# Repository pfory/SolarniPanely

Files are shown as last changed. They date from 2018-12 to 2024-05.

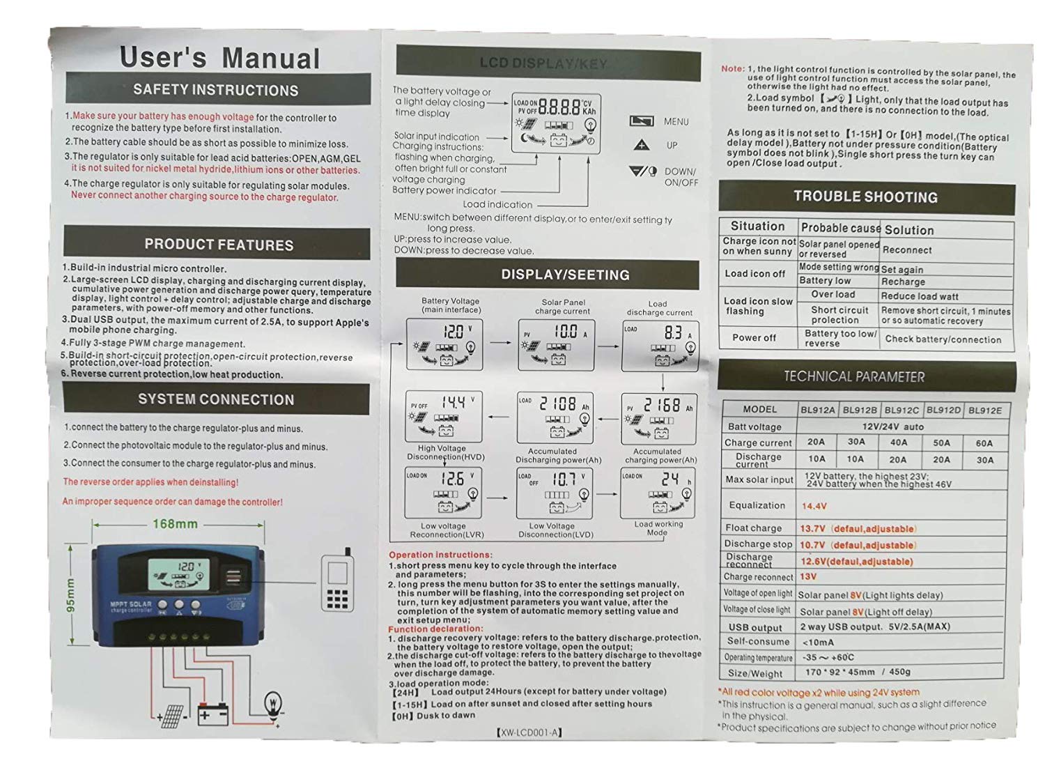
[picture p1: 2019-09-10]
fotovoltaika/manuál.jpg

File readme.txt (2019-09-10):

Odkazy
http://pavelrichter.net/category/projekty/fotovoltaika/
http://blog.chupasweb.net/archives/494
https://www.youtube.com/watch?v=ouLa4Ftu3O8¨

Popis
Solární panel z jednotlivých solárních článků. Ukládání přebytečné energie do baterie, použít autobaterii, později nahradit něčím lepším. Vyrobenou energii měnit na 230V a napájet spotřebiče

Co potřebuji
- solání články + kabely, ebay 5x5" 125x125mm, 2,7W/článek nominální napětí 0,55 - 0,6V/článek 
https://www.ebay.com/itm/2-8W-125MM-Monocrystalline-Solar-Cells-5x5-A-Grade-For-DIY-Solar-Panels/113344175030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
https://www.ebay.com/itm/40Pcs-125MM-Monocrystalline-Silicon-Solar-Cells-For-DIY-Solar-Panels/302911830537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
kolektor 100Wp cca 36ks 9*4 napětí 18V, proud 5,5A 		50ks cena cca 1383,- 
36 článků 996,-

4*125+3*10 =500+30  =530mm   +2*10  +2*19    = 530+20+38 =588mm     590   

9*125+8*1 =1125+8 =1133    +2*10    +2*19    = 1133+20+38=1191mm    1190
                    články  mezera rámeček

rámeček alu profil U 40x25x3 90/m
125+125+62+62=3,75m = 337,-

profil na 2 panely 987 + 140 doprava = 1127
1 panel 560,-

rám 670x1250
sklo 670-2x10=650
1250-2x10=1230

profil pro uchycení na střechu - https://www.ehlinik.cz/al-profil-solar-40x40/pro-2EV0000101.html
délka 2x67 + 2x67 = 4x67 = 268 + mezery 3x2 + kraje 2x5 = 268 + 16 = 284

pro 4 panely zapojené paralelně:
napětí 18V
proud 5,5*4=22A  měl by stačit vodič o průřezu 2,5
výkon 4x100Wp=400Wp

- alu profil https://www.alupa.cz/hlinik/hlinikovy-u-profil-nepr-11x25x13x18/pro-2YS0000101.html 225,-
- sklo 690/m2 panel cca 1m2 - 690,-
- silikon
- regulátor	400,- https://www.ebay.co.uk/itm/10-50A-12-24V-PWM-LCD-Automatic-Solar-Panel-Charger-Controller-Battery-Regulator/122717669692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
- baterie	autobaterie
- měnič 230V
- kabely
- diody
- konektory
- cín
- lepicí páska
- štětec
- nůžky
- ....

Nářadí
- pájka
- svěrák
- pila
- pilník
- šroubovák
- kladivo
- kleště
- klíče

Jeden 100W kolektor by měl za rok vyrobit 80kWh tj. při ceně 6Kč/kWh je cca 480,- za rok

Cenu kolektoru
články 996,-
sklo 782,-
alu profil 350,-
silikon 70,-
tištěné díly + šrouby 50,-

celkem 2248,-

Eko verze s EVA
články 780,-
alu profil 30x20x2 50,7 bez DPH - 3m = 184,-
alu profil 40x20x2 55,9         - 3m = 203,-
doprava 140,-
sklo 4mm cca 115x55 = 380,-
EVA 1000x500*0,4 1m 181,- = 362,-

celkem 780+200+400+362=1742,-

- regulátor 460,-

profil 40x25x3 - 1250
profil 40x25x3 - 620

1.panel
sklo 4mm 65*123
sklo 3mm 65*123
celkem 782,-

2.panel
sklo 4mm 
sklo 3mm 
celkem 782,-

ROZVOD
ze střechy kabelem 4mm do dílny
v dílně baterie, měnič, regulátor a UPS
230 z měniče přes spínací relé do rozvodu UPS
12V přes spínací relé do stávajícího rozvodu 12V

později
dokoupit panely 1 x 115Wp

první panel na střeše jaro 2019
druhý panel na střeše od 16.7.2019
třetí panel - koupeno 15.8.2019 cena 2490,- neosolar.cz na střeše od 20.8.2019

baterie + svorky - koupena 9.9.2019 1197,-

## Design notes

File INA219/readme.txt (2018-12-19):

float getBusVoltage_V(void);  

Reads the voltage between GND and V-.  This is the total voltage seen by the circuit under test.  (Supply voltage - shunt voltage).  

The return value is in Volts.

float getShuntVoltage_mV(void);  

Reads the voltage between V- and V+.  This is the measured voltage drop across the shunt resistor.  

The return value is in Milivolts.

float getCurrent_mA(void);

Reads the current, derived via Ohms Law from the measured shunt voltage.

The return value is in Milliamps.

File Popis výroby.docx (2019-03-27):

Solární články

Použil jsem solární články o rozměru 5x5 palce tj. 125*125mm. Tlouštka článku je 0,2mm a jsou velmi křehké proto je potřeba být při manipulaci maximálně opatrný. Články jsem objednal na ebay, přišly asi za 3týdny. Dodavatel byl sice z Číny, ale na balíčku byla německá adresa. Abych neplatil clo tak jsem rozdělil 50 kusů na dva balíčky ale dodavatel je stejně posla najednou. Cena je závislá na objednávaném množství a pohybuje kolem 20Kč za kus. Je možné objednat pouze články nebo současně i propojovací lišty a fixa s pájecí kapalinou. Tato kapalina usnadňuje pájení, bez ní to jde špatně. Šla by asi použít i klasická kalafuna ale její pozdější odstranění by bylo složitější.

Výkon jednoho článku je 2,8W, napětí kolem 0,5V. Obvykle se používá sériové zapojení 36 článků. Výkon panelu je pak 36*2,8=100W při napětí 18V.

Na články je potřeba naletovat sběrnicové vodiče, což je plochý, pocínovaný pásek o šířce asi 3mm. Ten je dodán navinutý na destičce a šířce jednoho článku takže pak stačí pásek stříhat na délku jednoho obtočení destičky. Při manipulaci s páskem se ho snažíme moc neopokřivit, lépe se pak bude pájet na články.

K pájení používám pájecí pero o výkonu 40W což je pro tento účel dostatečný výkon. Hrot volím co nejmasivnější kvůli akumulaci tepla a široký.

Článek má dvě strany, horní je kladný pól a má obvykle modrou nebo černou barvu, spodní je záporný pól a má obvykle šedou barvu. Na horní straně je po celé šířce článku pájecí ploška, obvykle jsou tam 2, ale mohou být i tři. Na spodní straně není tato pájecí plocha souvislá.

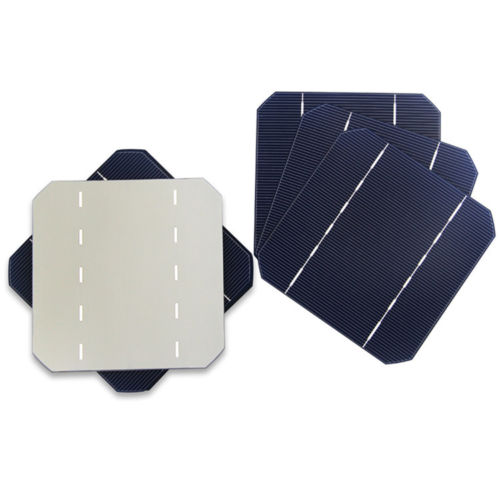
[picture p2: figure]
80Pcs-Mono-Solar-Cells-5x5-For-DIY-Solar-Panels

Solární články, vlevo spodní strana

Postup při pájení je následující:

- panel si položím na stůl kladným pólem nahoru tak aby pájecí plošky byly ve směru, kterým se dívám
- fixem potřu pájecí plošky
- odstřihnu jednu otočku sběrnicového vodiče
- položím na panel tak aby jeden konec byl asi 1 mm od kraje
- vyrovnám sběrnicový vodič tak aby byl nad pájecími ploškami
- zatížím sběrnicový vodič na obou koncích nějakým těžítkem
- na vzdálenější straně nahřeju a připájím asi 1cm sběrnicového vodiče
- odstraním těžítko co je blíž ke mně
- chytím sběrnicový vodič do prstů a začnu směrem k sobě od vzdálenějšího konce pájet
- koriguji umístění pásku

Takto si připravím články pro jeden sloupec. Jelikož jde o panel 36 článků, budou zde 4 sloupce po 9 článcích. Těchto 9 článků spojuji následovně:

- na stůl si položím první článek, záporným pólem nahoru. K němu musím naletovat sběrnicové vodiče, kterými se později připájí k hlavní sběrnici panelu. Tyto pásky jsou dlouhé jako článek s asi 4 cm přesahem. Pásky naletované dříve na kladný pól směřují ke mně.
- na pájecí plošky nanesu fixou pájecí kapalinu
- odstřižený pásek přiložím k první plošce a připájím
- postupně připájím i na ostatní plošky

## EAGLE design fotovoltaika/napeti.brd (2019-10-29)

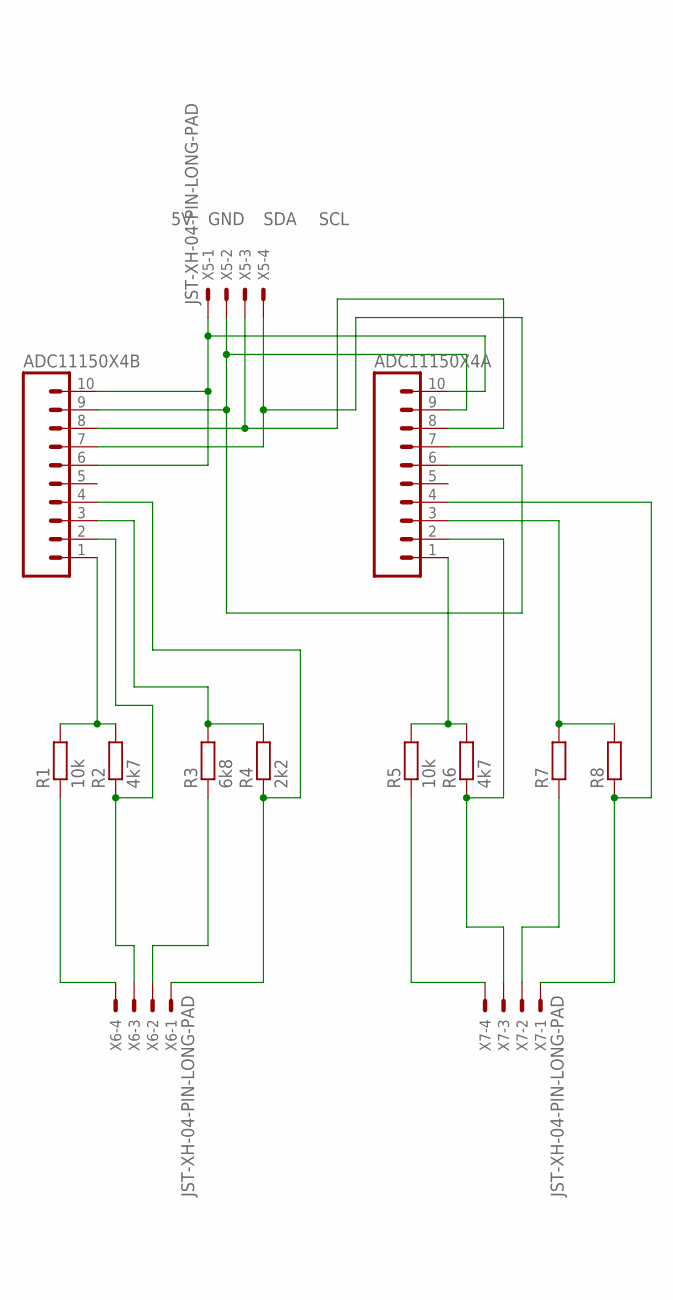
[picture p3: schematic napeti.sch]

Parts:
ADC11150X4A, ADC11150X4B: M10; 10P
R1, R5: 10k; 0204/7
R2, R6: 4k7; 0204/7
R3: 6k8; 0204/7
R4: 2k2; 0204/7
R7, R8: R-EU_0204/7; 0204/7
X5, X6, X7: JST-XH-04-PIN-LONG-PAD; JST-XH-04-PACKAGE-LONG-PAD

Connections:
5V: ADC11150X4A.10, ADC11150X4B.6, ADC11150X4B.10, X5.1
GND: ADC11150X4A.6, ADC11150X4A.9, ADC11150X4B.9, X5.2
unnamed: ADC11150X4A.1, R5.2, R6.2
unnamed: R1.1, X6.4
unnamed: ADC11150X4A.2, R6.1, X7.3
unnamed: ADC11150X4A.3, R7.2, R8.2
unnamed: R3.1, X6.2
unnamed: ADC11150X4A.4, R8.1, X7.1
unnamed: R5.1, X7.4
unnamed: R7.1, X7.2
unnamed: ADC11150X4B.1, R1.2, R2.2
unnamed: ADC11150X4B.2, R2.1, X6.3
unnamed: ADC11150X4B.3, R3.2, R4.2
unnamed: ADC11150X4B.4, R4.1, X6.1
SCL: ADC11150X4A.7, ADC11150X4B.7, X5.4
SDA: ADC11150X4A.8, ADC11150X4B.8, X5.3

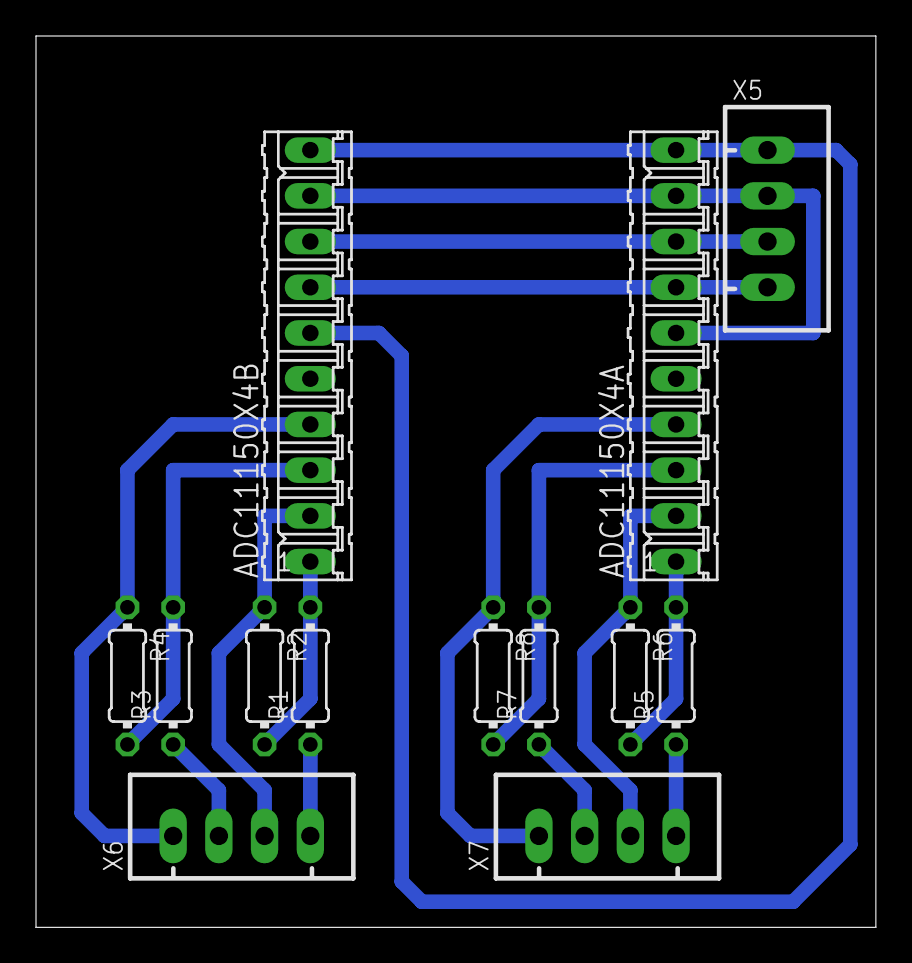
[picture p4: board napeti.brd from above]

Board: 2 copper layers, 46.7 x 49.5 mm, 13 parts (0 on the bottom side), 16 nets.

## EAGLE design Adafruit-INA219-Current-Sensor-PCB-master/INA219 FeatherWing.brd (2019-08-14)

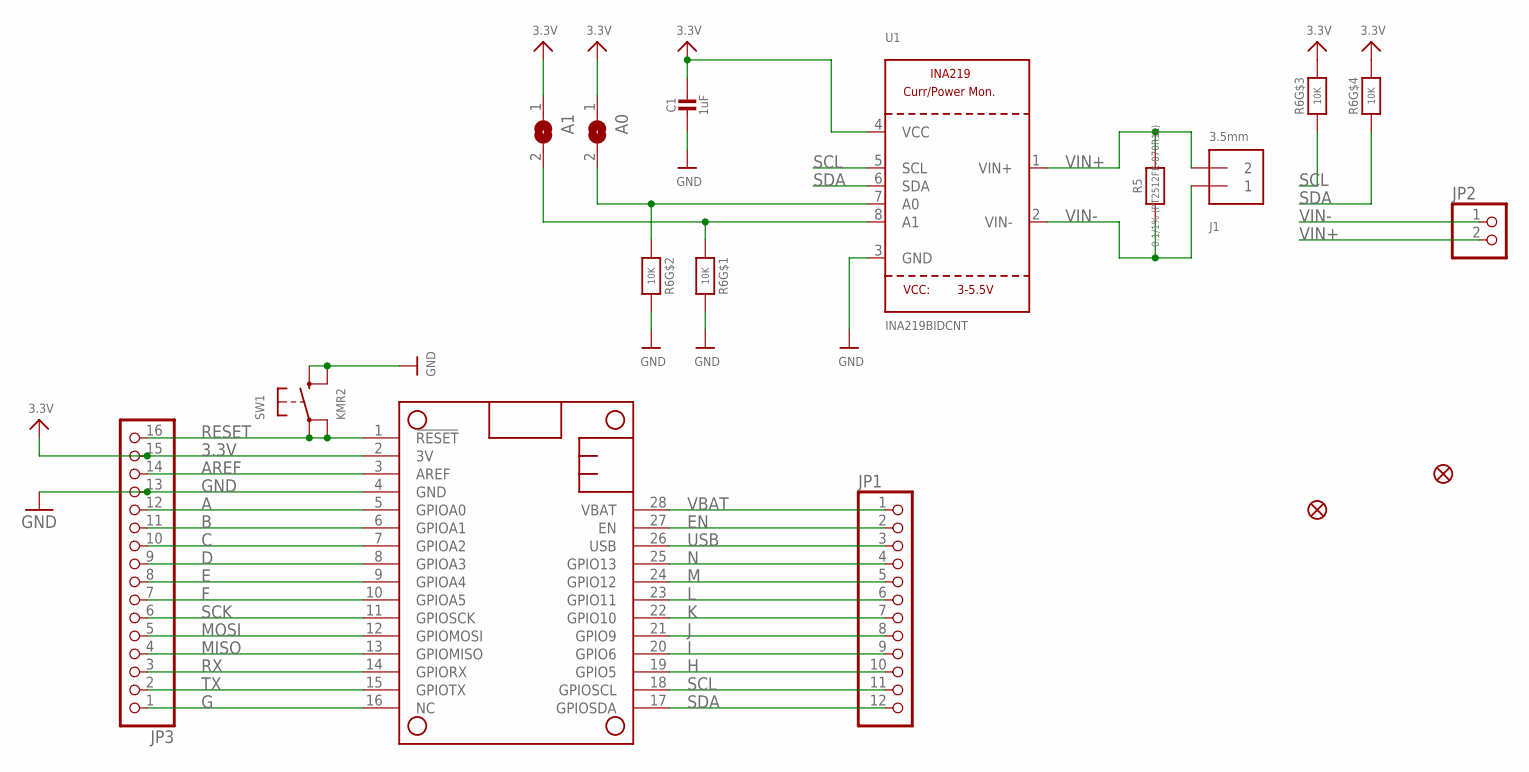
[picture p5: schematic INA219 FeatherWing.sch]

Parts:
A0, A1: SOLDERJUMPERREFLOW_NOPASTE; SOLDERJUMPER_REFLOW_NOPASTE
C1: 1uF; 0805-NO@1
FID1, FID2: FIDUCIAL_1MM
J1: 3.5mm; TERMBLOCK_1X2-3.5MM
JP1: HEADER-1X1276MIL; 1X12_ROUND_76MIL
JP2: HEADER-1X2ROUND; 1X02_ROUND
JP3: HEADER-1X16_76MIL; 1X16_ROUND_76MIL
MS1: FEATHERWING
R5: 0.1/1% (PT2512FK-070R1L); 2512
R6: 10K; RESPACK_4X0603
SW1: KMR2; BTN_KMR2_4.6X2.8
U1: INA219BIDCNT; SOT23-8

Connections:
3.3V: A0.1, A1.1, C1.1, JP3.15, MS1.2 (3V), R6.5 (2), R6.6 (2), U1.4 (VCC)
A: JP3.12, MS1.5 (GPIOA0)
AREF: JP3.14, MS1.3 (AREF)
B: JP3.11, MS1.6 (GPIOA1)
C: JP3.10, MS1.7 (GPIOA2)
D: JP3.9, MS1.8 (GPIOA3)
E: JP3.8, MS1.9 (GPIOA4)
EN: JP1.2, MS1.27 (EN)
F: JP3.7, MS1.10 (GPIOA5)
G: JP3.1, MS1.16 (NC)
GND: C1.2, JP3.13, MS1.4 (GND), R6.7 (2), R6.8 (2), SW1.B (S), SW1.B' (S1), U1.3 (GND)
H: JP1.10, MS1.19 (GPIO5)
I: JP1.9, MS1.20 (GPIO6)
J: JP1.8, MS1.21 (GPIO9)
K: JP1.7, MS1.22 (GPIO10)
L: JP1.6, MS1.23 (GPIO11)
M: JP1.5, MS1.24 (GPIO12)
MISO: JP3.4, MS1.13 (GPIOMISO)
MOSI: JP3.5, MS1.12 (GPIOMOSI)
N: JP1.4, MS1.25 (GPIO13)
unnamed: A1.2, R6.1, U1.8 (A1)
unnamed: A0.2, R6.2 (1), U1.7 (A0)
RESET: JP3.16, MS1.1 (!RESET), SW1.A, SW1.A' (P1)
RX: JP3.3, MS1.14 (GPIORX)
SCK: JP3.6, MS1.11 (GPIOSCK)
SCL: JP1.11, MS1.18 (GPIOSCL), R6.3 (1), U1.5 (SCL)
SDA: JP1.12, MS1.17 (GPIOSDA), R6.4 (1), U1.6 (SDA)
TX: JP3.2, MS1.15 (GPIOTX)
USB: JP1.3, MS1.26 (USB)
VBAT: JP1.1, MS1.28 (VBAT)
VIN+: J1.2, JP2.2, R5.2, U1.1 (VIN+)
VIN-: J1.1, JP2.1, R5.1, U1.2 (VIN-)

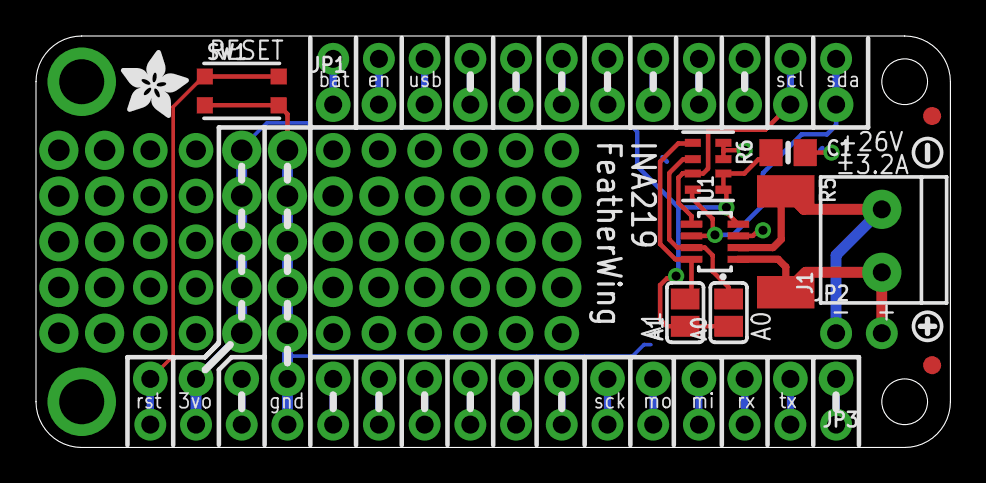
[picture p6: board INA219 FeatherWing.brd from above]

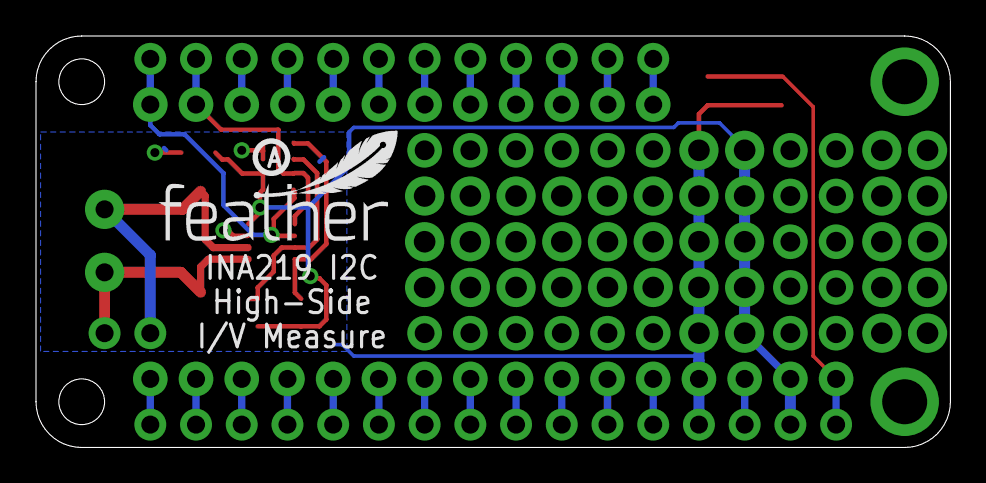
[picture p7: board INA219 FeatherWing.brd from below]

Board: 2 copper layers, 50.8 x 22.9 mm, 19 parts (2 on the bottom side), 32 nets.

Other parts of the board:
U$12: SYMBOL_PLUS
U$13: SYMBOL_MINUS
U$15: FEATHERLOGO_SMALL
U$16: ADAFRUIT_3.5MM
U$17: PCBFEAT-REV-040

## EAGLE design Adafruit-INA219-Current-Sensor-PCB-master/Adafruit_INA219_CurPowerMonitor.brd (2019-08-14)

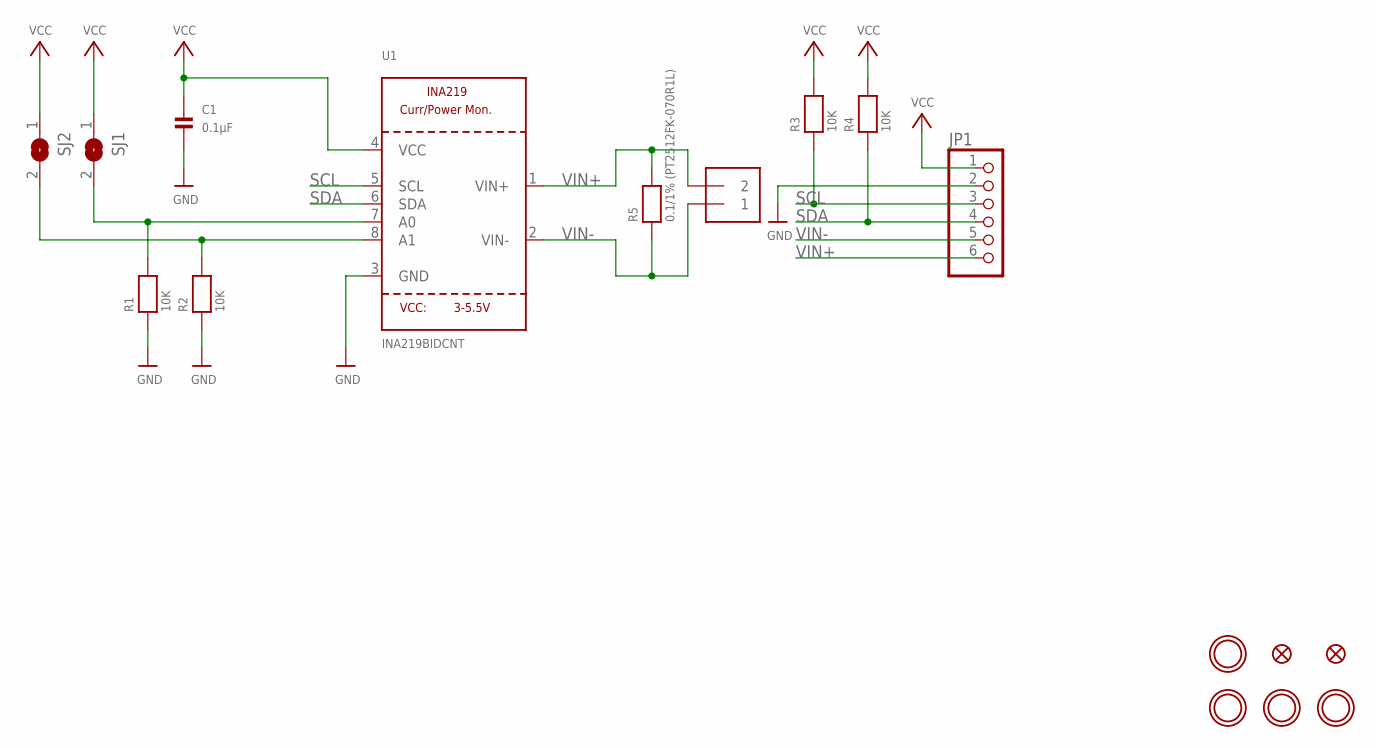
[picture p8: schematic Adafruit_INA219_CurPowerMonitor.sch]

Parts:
C1: 0.1µF; 0805
FID1, FID2: FIDUCIAL""; FIDUCIAL_1MM
J1: TERMBLOCK_1X2-3.5MM; 1X2-3.5MM
JP1: HEADER-1X670MIL; 1X06_ROUND_70
R1, R2, R3, R4: 10K; 0805
R5: 0.1/1% (PT2512FK-070R1L); 2512
SJ1, SJ2: SOLDERJUMPERREFLOW_NOPASTE; SOLDERJUMPER_REFLOW_NOPASTE
U1: INA219BIDCNT; SOT23-8
U$7, U$8, U$9, U$10: MOUNTINGHOLE2.5; MOUNTINGHOLE_2.5_PLATED

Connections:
GND: C1.2, JP1.2, R1.1, R2.1, U1.3 (GND)
unnamed: R2.2, SJ2.2, U1.8 (A1)
unnamed: R1.2, SJ1.2, U1.7 (A0)
SCL: JP1.3, R3.1, U1.5 (SCL)
SDA: JP1.4, R4.1, U1.6 (SDA)
VCC: C1.1, JP1.1, R3.2, R4.2, SJ1.1, SJ2.1, U1.4 (VCC)
VIN+: J1.2, JP1.6, R5.2, U1.1 (VIN+)
VIN-: J1.1, JP1.5, R5.1, U1.2 (VIN-)

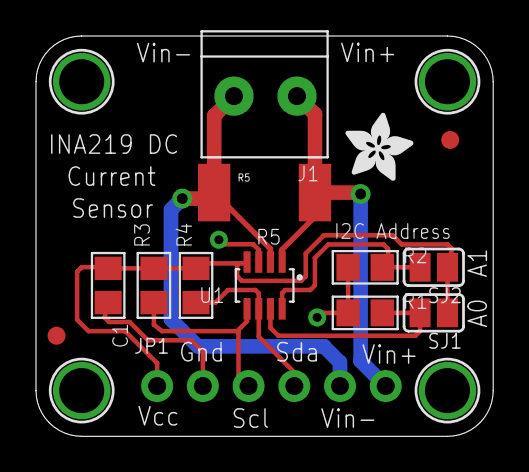
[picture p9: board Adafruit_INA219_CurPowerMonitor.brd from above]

Board: 2 copper layers, 25.4 x 22.2 mm, 18 parts (0 on the bottom side), 8 nets.

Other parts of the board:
U$11: ADAFRUIT_3.5MM

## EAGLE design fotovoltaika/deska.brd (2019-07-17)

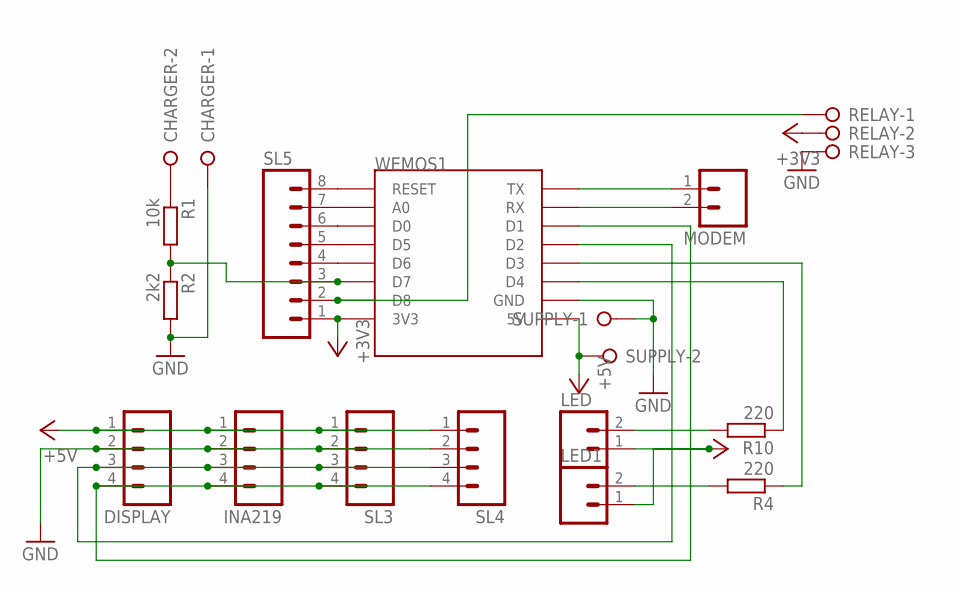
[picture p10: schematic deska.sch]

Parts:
CHARGER: W237-02P; W237-132
DISPLAY: M04; 04P
INA219: M04; 04P
LED, LED1: M02; 02P
MODEM: M02; 02P
R1: 10k; 0207/10
R2: 2k2; 0207/10
R4, R10: 220; 0207/10
RELAY: W237-3E
SL3, SL4: M04; 04P
SL5: M08; 08P
SUPPLY: W237-02P; W237-132
WEMOS1: WEMOS-D1-MINI

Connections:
+3V3: RELAY.2, SL5.1, WEMOS1.3V3
+5V: DISPLAY.1, INA219.1, LED.1, LED1.1, SL3.1, SL4.1, SUPPLY.2, WEMOS1.5V
GND: CHARGER.1, DISPLAY.2, INA219.2, R2.2, RELAY.3, SL3.2, SL4.2, SUPPLY.1, WEMOS1.GND
unnamed: DISPLAY.4, INA219.4, SL3.4, SL4.4, WEMOS1.D1
unnamed: DISPLAY.3, INA219.3, SL3.3, SL4.3, WEMOS1.D2
unnamed: SL5.7, WEMOS1.A0
unnamed: RELAY.1, SL5.2, WEMOS1.D8
unnamed: CHARGER.2, R1.1
unnamed: SL5.4, WEMOS1.D6
unnamed: SL5.5, WEMOS1.D5
unnamed: SL5.6, WEMOS1.D0
unnamed: R1.2, R2.1, SL5.3, WEMOS1.D7
unnamed: R10.1, WEMOS1.D4
unnamed: LED.2, R10.2
unnamed: SL5.8, WEMOS1.RESET
unnamed: MODEM.1, WEMOS1.TX
unnamed: MODEM.2, WEMOS1.RX
unnamed: LED1.2, R4.2
unnamed: R4.1, WEMOS1.D3

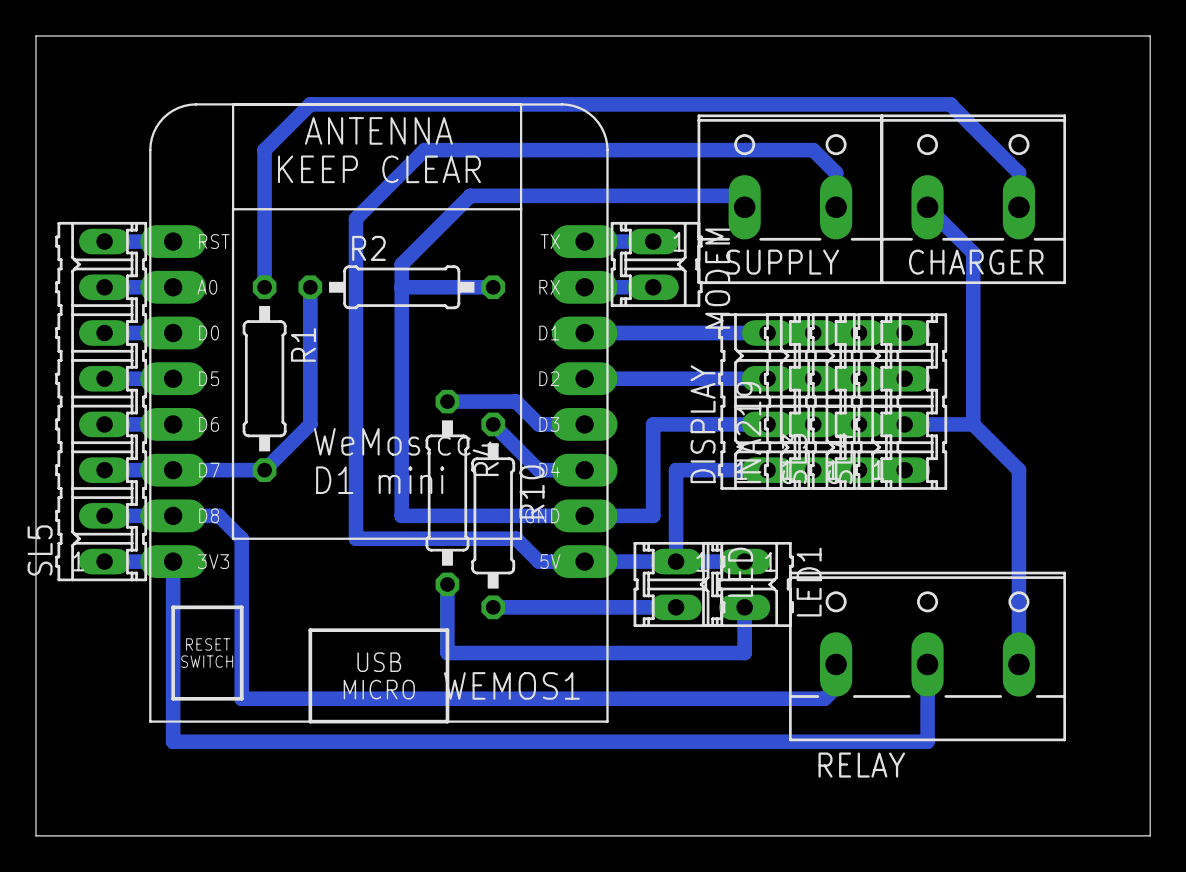
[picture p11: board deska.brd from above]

Board: 2 copper layers, 61.9 x 44.4 mm, 16 parts (0 on the bottom side), 19 nets.

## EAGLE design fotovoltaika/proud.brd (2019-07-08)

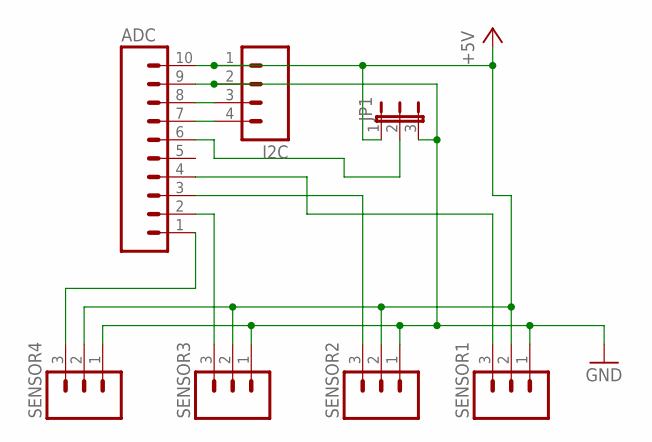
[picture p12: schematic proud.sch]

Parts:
ADC: M10; 10P
I2C: M04; 04P
JP1: JP2E; JP2
SENSOR1, SENSOR2, SENSOR3, SENSOR4: M03; 03P

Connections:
+5V: ADC.10, I2C.1, JP1.1, SENSOR1.2, SENSOR2.2, SENSOR3.2, SENSOR4.2
GND: ADC.9, I2C.2, JP1.3, SENSOR1.1, SENSOR2.1, SENSOR3.1, SENSOR4.1
unnamed: ADC.1, SENSOR4.3
unnamed: ADC.8, I2C.3
unnamed: ADC.2, SENSOR3.3
unnamed: ADC.3, SENSOR2.3
unnamed: ADC.4, SENSOR1.3
unnamed: ADC.7, I2C.4
unnamed: ADC.6, JP1.2

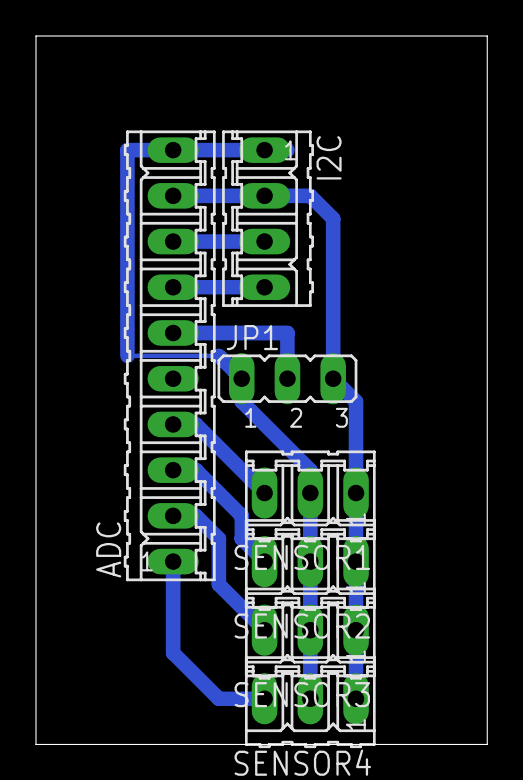
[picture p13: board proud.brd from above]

Board: 2 copper layers, 25.1 x 39.4 mm, 7 parts (0 on the bottom side), 9 nets.

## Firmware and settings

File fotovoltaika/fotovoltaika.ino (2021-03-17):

/*HW
  mereni proudu na regulatoru
    - vstup z FW panelu, cidlo s  ACS758LCB-050B +-50A  40mV/A
    - akumulator, cidlo s         ACS712 +-20A          100mV/A
    - vystup, cidlo s             ACS712 +-5A           185mV/A
    vsechna cidla jsou pripojena na vstupy AD prevodniku s ADS1115, vystup I2C SDA - D2, SCL - D1
  mereni napeti na regulatoru, spolecny je + pol, proti zemi je max na vstupu z panelu tj.20V

 
  display - 20x4
  ESP8266 - Wemos
  
  větev baterie - měnič
  odběr na prázdno      0,18A   2,2W
  bez čerpadla soláru   1,36A  16,3W
  s čerpadlem soláru    3,87A  46,5W
  
*/

#include "Configuration.h"

#define time
#ifdef time
#include <TimeLib.h>
#include <Timezone.h>
WiFiUDP EthernetUdp;
static const char     ntpServerName[]       = "tik.cesnet.cz";
//const int timeZone = 2;     // Central European Time
//Central European Time (Frankfurt, Paris)
TimeChangeRule        CEST                  = {"CEST", Last, Sun, Mar, 2, 120};     //Central European Summer Time
TimeChangeRule        CET                   = {"CET",  Last, Sun, Oct, 3, 60 };     //Central European Standard Time
Timezone CE(CEST, CET);
unsigned int          localPort             = 8888;  // local port to listen for UDP packets
time_t getNtpTime();
#define TIMEX   0
#define TIMEY   3
#endif

//voltage and current meassurement
Adafruit_ADS1115 ads1(0x48);  //mereni proudu ADDR to GND - pravý
Adafruit_ADS1115 ads2(0x49);  //mereni napeti ADDR to VCC - levý
//Adafruit_ADS1115 ads3(0x4B);  //mereni napeti ADDR to SCL


#include <LiquidCrystal_I2C.h>
LiquidCrystal_I2C lcd(LCDADDRESS,LCDCOLS,LCDROWS);  // set the LCD
#define PRINT_SPACE  lcd.print(" ");
volatile bool showDoubleDot                 = false;
unsigned int display                        = 0;
#define DISPLAY_MAIN                         0

//navrhar - https://maxpromer.github.io/LCD-Character-Creator/
byte customChar[] = {
  B01110,
  B01010,
  B01110,
  B00000,
  B00000,
  B00000,
  B00000,
  B00000
};

//for LED status
Ticker ticker;

bool isDebugEnabled()
{
#ifdef verbose
  return true;
#endif // verbose
  return false;
}


float   relayONVoltageBig           = 13.5;
float   relayONVoltageSmall         = 12.5;
float   relayOFFVoltage             = 11.f;


byte relayStatus                    = RELAY_OFF;
byte relayMode                      = RELAY_MODE_AUTO;
  
int duvodZmenyStavuRele             = 0;
//ADC_MODE(ADC_VCC);

uint32_t heartBeat                  = 0;

//mereni napeti   
float      voltageRegInMin          = MAX; //vystup z panelu, rozsah 0-20V
float      voltageRegIn             = 12.f; 
float      voltageRegOutMin         = MAX; //vystup z regulatoru, rozsah 0-15V
float      voltageRegInMax          = MIN; //vystup z panelu, rozsah 0-20V
float      voltageRegOutMax         = MIN; //vystup z regulatoru, rozsah 0-15V
float      voltageRegOut            = 12.f; 
float      voltageSupply            = MIN;
float      forecastedEnergyTomorrow = -1.f;  
uint32_t  lastReadADC               = 0;              //interval mezi ctenim sensoru

//mereni proudu
float     currentRegIn              = 0.f;   //Ampers
float     currentRegOut             = 0.f;
      
float     currentRegInSum           = 0.f;
float     currentRegOutSum          = 0.f;
int32_t   intervalMSec              = 0;

long      runSecToday               = 0;
float     AhPanelToday              = 0;
float     AhOutToday                = 0;

bool      todayClear                = false;
bool      dispClear                 = false;

float     lastRelayOff              = 0;


DoubleResetDetector drd(DRD_TIMEOUT, DRD_ADDRESS);


//Adafruit_INA219 ina219_2; //intput
//Adafruit_INA219 ina219_1(0x41); //output

//gets called when WiFiManager enters configuration mode
void configModeCallback (WiFiManager *myWiFiManager) {
  DEBUG_PRINTLN("Entered config mode");
  DEBUG_PRINTLN(WiFi.softAPIP());
  //if you used auto generated SSID, print it
  DEBUG_PRINTLN(myWiFiManager->getConfigPortalSSID());
  //entered config mode, make led toggle faster
  ticker.attach(0.2, tick);
  drd.stop();
}

#include <timer.h>
auto timer = timer_create_default(); // create a timer with default settings
Timer<> default_timer; // save as above


void tick()
{
  //toggle state
  int state = digitalRead(BUILTIN_LED);  // get the current state of GPIO1 pin
  digitalWrite(BUILTIN_LED, !state);     // set pin to the opposite state
  digitalWrite(STATUS_LED, !state);          // set pin to the opposite state
}


//MQTT callback
void callback(char* topic, byte* payload, unsigned int length) {
  char * pEnd;
  long int valL;
  String val =  String();
  DEBUG_PRINT("Message arrived [");
  DEBUG_PRINT(topic);
  DEBUG_PRINT("] ");
  for (int i=0;i<length;i++) {
    DEBUG_PRINT((char)payload[i]);
    val += (char)payload[i];
  }
  DEBUG_PRINTLN();
  
  if (strcmp(topic, (String(mqtt_base) + "/cmnd/" + String(mqtt_topic_relay)).c_str())==0) {
    printMessageToLCD(topic, val);
    DEBUG_PRINT("set manual control relay to ");
    relayMode = val.toInt();
    if (val.toInt()==1) {
      DEBUG_PRINTLN(F("ON"));
    } else if (val.toInt()==0) {
      DEBUG_PRINTLN(F("OFF"));
    } else {
      DEBUG_PRINTLN(F("AUTO"));
    }
  } else if (strcmp(topic, (String(mqtt_base) + "/" + String(mqtt_topic_restart)).c_str())==0) {
    printMessageToLCD(topic, val);
    DEBUG_PRINT("RESTART");
    ESP.restart();
  } else if (strcmp(topic, mqtt_topic_weather)==0) {
    DEBUG_PRINT("Temperature from Meteo: ");
    DEBUG_PRINTLN(val.toFloat());
    //displayValue(TEMPERATURE_X,TEMPERATURE_Y, (int)round(val.toFloat()), 3, 0);
    //lcd.write(byte(0));
    //lcd.print("C");
  } else if (strcmp(topic, (String(mqtt_base) + "/" + String(mqtt_topic_relayOFFVoltage)).c_str())==0) {
    printMessageToLCD(topic, val);
    DEBUG_PRINT("set OFF voltage to ");
    relayOFFVoltage = val.toFloat();
    saveConfig();
  } else if (strcmp(topic, (String(mqtt_base) + "/" + String(mqtt_topic_relayONVoltageBig)).c_str())==0) {
    printMessageToLCD(topic, val);
    DEBUG_PRINT("set ON big voltage to ");
    relayONVoltageBig = val.toFloat();
    saveConfig();
  } else if (strcmp(topic, (String(mqtt_base) + "/" + String(mqtt_topic_forecast)).c_str())==0) {
    DEBUG_PRINT("Forecast from solcast ");
    lcd.setCursor(FORECAST_X-3,FORECAST_Y);
    lcd.print("FP:");
    displayValue(FORECAST_X,FORECAST_Y, val.toFloat(), 2, 1);
    forecastedEnergyTomorrow = val.toFloat();
    lcd.print("kWh");
  } else if (strcmp(topic, (String(mqtt_base) + "/" + String(mqtt_topic_relayONVoltageSmall)).c_str())==0) {
    printMessageToLCD(topic, val);
    DEBUG_PRINT("set ON small voltage to ");
    relayONVoltageSmall = val.toFloat();
    saveConfig();
  }
}

void printMessageToLCD(char* t, String v) {
  lcd.clear();
  lcd.print(t);
  lcd.print(": ");
  lcd.print(v);
  delay(2000);
  lcd.clear();
}


WiFiClient espClient;
PubSubClient client(espClient);

void setup() {
  SERIAL_BEGIN;
  DEBUG_PRINT(F(SW_NAME));
  DEBUG_PRINT(F(" "));
  DEBUG_PRINTLN(F(VERSION));

  WiFiManager wifiManager;

  if (drd.detectDoubleReset()) {
    DEBUG_PRINTLN("Double reset detected, starting config portal...");
    if (!wifiManager.startConfigPortal(HOSTNAMEOTA)) {
      DEBUG_PRINTLN("failed to connect and hit timeout");
      delay(3000);
      //reset and try again, or maybe put it to deep sleep
      ESP.reset();
      delay(5000);
    }
  }

  lcd.init();               // initialize the lcd 
  lcd.backlight();
  //lcd.begin();               // initialize the lcd 
  lcd.home();                   
  lcd.print(SW_NAME);  
  PRINT_SPACE
  lcd.print(VERSION);
  lcd.createChar(0, customChar);

  pinMode(BUILTIN_LED, OUTPUT);
  pinMode(STATUS_LED, OUTPUT);
  pinMode(LED2PIN, OUTPUT);
  digitalWrite(STATUS_LED, HIGH); //nesviti
  digitalWrite(LED2PIN, HIGH);
  pinMode(RELAY1PIN, OUTPUT);
  pinMode(RELAY2PIN, OUTPUT);
  digitalWrite(RELAY1PIN, relayStatus);
  digitalWrite(RELAY2PIN, relayStatus);
  pinMode(PIRPIN, INPUT);
  //attachInterrupt(digitalPinToInterrupt(PIRPIN), PIREvent, CHANGE);

  rst_info *_reset_info = ESP.getResetInfoPtr();
  uint8_t _reset_reason = _reset_info->reason;
  DEBUG_PRINT("Boot-Mode: ");
  DEBUG_PRINTLN(_reset_reason);
  heartBeat = _reset_reason;
  
  /*
 REASON_DEFAULT_RST             = 0      normal startup by power on 
 REASON_WDT_RST                 = 1      hardware watch dog reset 
 REASON_EXCEPTION_RST           = 2      exception reset, GPIO status won't change 
 REASON_SOFT_WDT_RST            = 3      software watch dog reset, GPIO status won't change 
 REASON_SOFT_RESTART            = 4      software restart ,system_restart , GPIO status won't change 
 REASON_DEEP_SLEEP_AWAKE        = 5      wake up from deep-sleep 
 REASON_EXT_SYS_RST             = 6      external system reset 
  */
  client.setServer(mqtt_server, mqtt_port);
  client.setCallback(callback);

  ticker.attach(1, tick);

  WiFi.printDiag(Serial);
    
  bool validConf = readConfig();
  if (!validConf) {
    DEBUG_PRINTLN(F("ERROR config corrupted"));
  }
  
  //reset settings - for testing
  //wifiManager.resetSettings();
  
  IPAddress _ip,_gw,_sn;
  _ip.fromString(static_ip);
  _gw.fromString(static_gw);
  _sn.fromString(static_sn);

  wifiManager.setSTAStaticIPConfig(_ip, _gw, _sn);
  
  DEBUG_PRINTLN(_ip);
  DEBUG_PRINTLN(_gw);
  DEBUG_PRINTLN(_sn);

  wifiManager.setConfigPortalTimeout(CONFIG_PORTAL_TIMEOUT);
  wifiManager.setConnectTimeout(CONNECT_TIMEOUT);
  //set callback that gets called when connecting to previous WiFi fails, and enters Access Point mode
  wifiManager.setAPCallback(configModeCallback);

  if (!wifiManager.autoConnect(AUTOCONNECTNAME, AUTOCONNECTPWD)) { 
    DEBUG_PRINTLN("failed to connect and hit timeout");
    delay(3000);
    //reset and try again, or maybe put it to deep sleep
    ESP.reset();
    delay(5000);
  } 
  
#ifdef time
  DEBUG_PRINTLN("Setup TIME");
  lcd.setCursor(0,1);
  lcd.print("Setup time...");
  EthernetUdp.begin(localPort);
  DEBUG_PRINT("Local port: ");
  DEBUG_PRINTLN(EthernetUdp.localPort());
  DEBUG_PRINTLN("waiting for sync");
  setSyncProvider(getNtpTime);
  setSyncInterval(300);
  
  printSystemTime();
#endif

  
#ifdef ota
  ArduinoOTA.setHostname(HOSTNAMEOTA);
  ArduinoOTA.onStart([]() {
    DEBUG_PRINTLN("Start updating ");
  });
  ArduinoOTA.onEnd([]() {
   DEBUG_PRINTLN("\nEnd");
  });
  ArduinoOTA.onProgress([](unsigned int progress, unsigned int total) {
    DEBUG_PRINTF("Progress: %u%%\r", (progress / (total / 100)));
  });
  ArduinoOTA.onError([](ota_error_t error) {
    DEBUG_PRINTF("Error[%u]: ", error);
    if (error == OTA_AUTH_ERROR) DEBUG_PRINTLN("Auth Failed");
    else if (error == OTA_BEGIN_ERROR) DEBUG_PRINTLN("Begin Failed");
    else if (error == OTA_CONNECT_ERROR) DEBUG_PRINTLN("Connect Failed");
    else if (error == OTA_RECEIVE_ERROR) DEBUG_PRINTLN("Receive Failed");
    else if (error == OTA_END_ERROR) DEBUG_PRINTLN("End Failed");
  });
  ArduinoOTA.begin();
#endif

  // The ADC input range (or gain) can be changed via the following
  // functions, but be careful never to exceed VDD +0.3V max, or to
  // exceed the upper and lower limits if you adjust the input range!
  // Setting these values incorrectly may destroy your ADC!
  //ADS1015 - 12bit = 4096
  //ADS1115 - 16bit = 65536
  //                                                             ADS1015         ADS1115
  //                                                             -------         -------
  ads1.setGain(GAIN_TWOTHIRDS);        // 2/3x gain +/- 6.144V  1 bit = 3mV      0.1875mV (default)
  ads2.setGain(GAIN_TWOTHIRDS);        // 2/3x gain +/- 6.144V  1 bit = 3mV      0.1875mV (default)
  //ads3.setGain(GAIN_TWOTHIRDS);        // 2/3x gain +/- 6.144V  1 bit = 3mV      0.1875mV (default)
  // ads.setGain(GAIN_ONE);            // 1x gain   +/- 4.096V  1 bit = 2mV      0.125mV
  // ads.setGain(GAIN_TWO);            // 2x gain   +/- 2.048V  1 bit = 1mV      0.0625mV
  // ads.setGain(GAIN_FOUR);           // 4x gain   +/- 1.024V  1 bit = 0.5mV    0.03125mV
  // ads.setGain(GAIN_EIGHT);          // 8x gain   +/- 0.512V  1 bit = 0.25mV   0.015625mV
  // ads.setGain(GAIN_SIXTEEN);        // 16x gain  +/- 0.256V  1 bit = 0.125mV  0.0078125mV
  ads1.begin();
  ads2.begin();
  //ads3.begin();
  
    // Initialize the INA219.
  // By default the initialization will use the largest range (32V, 2A).  However
  // you can call a setCalibration function to change this range (see comments).
  //ina219_1.begin();
  //ina219_2.begin();
  // To use a slightly lower 32V, 1A range (higher precision on amps):
  //ina219_1.setCalibration_16V_400mA();
  //ina219_2.setCalibration_32V_2A();
  // Or to use a lower 16V, 400mA range (higher precision on volts and amps):
  //ina219.setCalibration_16V_400mA();
  
  //setup timers
  timer.every(SEND_DELAY, sendDataHA);
  timer.every(SENDSTAT_DELAY, sendStatisticHA);
  timer.every(READADC_DELAY, readADC);
  timer.every(1000, calcStat);
#ifdef time  
  timer.every(500, displayTime);
#endif
  void * a;
  sendStatisticHA(a);

  ticker.detach();
  //keep LED on
  digitalWrite(BUILTIN_LED, HIGH);
  digitalWrite(STATUS_LED, HIGH);
  lcd.clear();
  lcd.setCursor(RELAY_STATUSX,RELAY_STATUSY);
  lcd.print("OFF");
}

void loop() {
  drd.loop();
  timer.tick(); // tick the timer
#ifdef ota
  ArduinoOTA.handle();
#endif

  if (digitalRead(PIRPIN)==1) {
    lcd.backlight();
  } else {
    lcd.noBacklight();
  }

  if (!client.connected()) {
    reconnect();
  }
  client.loop();

  relay();
 
  nulStat();
  displayClear();

  drd.stop();
 
}

//---------------------------------------------R E L A Y ------------------------------------------------
void relay() {
  if (relayMode==RELAY_MODE_AUTO) {
    if (millis() - lastRelayOff > RELAYDELAYOFFON) {
      //-----------------------------------zmena 0-1--------------------------------------------
      if (relayStatus == RELAY_OFF) {
        bool zapni=false;
        if (voltageRegOut > relayONVoltageBig) { //voltageRegOut > 13.5
          duvodZmenyStavuRele=1;
          zapni = true;
        } else if (currentRegIn > CURRENT4ONBIG) { //currentRegIn > 6
          duvodZmenyStavuRele=2;
          zapni = true;
        } else if (currentRegIn > CURRENT4ONSMALL && voltageRegOut >= relayONVoltageSmall) { //currentRegIn > 4) && voltageRegOut >= 12.5
          duvodZmenyStavuRele=3;
          zapni = true;
        }
        if (zapni) {
          relayStatus = RELAY_ON;
          changeRelay(relayStatus);
          sendRelayHA(1);
        }
      //-----------------------------------zmena 1-0--------------------------------------------
      } else if (relayStatus == RELAY_ON) {
        bool vypni=false;
        if (voltageRegOut <= relayOFFVoltage) { //voltageRegOut <= 11.0
          duvodZmenyStavuRele=4;
          vypni = true;
        } else if (forecastedEnergyTomorrow < FORECASTED_LIMIT_OFF && currentRegIn < CURRENT4ONSMALL && voltageRegOut < relayONVoltageSmall) { //forecastedEnergyTomorrow < 0.06 && currentRegIn < 2 && voltageRegOut < 12.5
          duvodZmenyStavuRele=5;
          vypni = true;
        //} else if (currentRegIn < currentRegOut && voltageRegOut < relayONVoltageSmall) { //currentRegIn < currentRegOut && voltageRegOut < 12.5
        //  duvodZmenyStavuRele=6;
        //  vypni = true;
        }
        if (vypni) {
          relayStatus = RELAY_OFF;
          changeRelay(relayStatus);
          sendRelayHA(0);
          lastRelayOff = millis();
        }
      }
      if (duvodZmenyStavuRele==-1) {
        duvodZmenyStavuRele=0;
      }
    } else {
      duvodZmenyStavuRele=-1;
    }
  } else if (relayStatus == RELAY_OFF && relayMode==RELAY_MODE_ON) {
      relayStatus = RELAY_ON;
      changeRelay(relayStatus);
      duvodZmenyStavuRele=7;
      sendRelayHA(1);
  } else if (relayStatus == RELAY_ON && relayMode==RELAY_MODE_OFF) {
      relayStatus = RELAY_OFF;
      changeRelay(relayStatus);
      duvodZmenyStavuRele=8;
      sendRelayHA(1);
  }
  dispRelayStatus();
}


void nulStat() {
 //nulovani statistik o pulnoci
  if (hour()==0 && !todayClear) {
    todayClear =true;
    runSecToday = 0;
    AhPanelToday = 0;
  } else if (hour()>0) {
    todayClear = false;
  }
}

void displayClear() {
  if (minute()==0 && second()==0) {
    if (!dispClear) { 
      lcd.clear();
      dispClear = true;
    }
  } else {
    dispClear = false;
  }
}

bool readADC(void *) {

  int32_t dilkuSupply            = ads1.readADC_SingleEnded(CHANNEL_VOLTAGE_SUPPLY);
  int32_t dilkuInputCurrent      = ads1.readADC_SingleEnded(CHANNEL_REG_IN_CURRENT);
  int32_t dilkuOutputCurrent     = ads1.readADC_SingleEnded(CHANNEL_REG_OUT_CURRENT);
  // DEBUG_PRINT("dilkuSupply:");
  // DEBUG_PRINT(dilkuSupply);
  // DEBUG_PRINT(", dilkuInputCurrent:");
  // DEBUG_PRINT(dilkuInputCurrent);
  // DEBUG_PRINT(", dilkuOutputCurrent:");
  // DEBUG_PRINTLN(dilkuOutputCurrent);
  
  voltageSupply    = ((float)dilkuSupply * MVOLTDILEKADC1); //in mV  example 26149 * 0.1875 = 4902,938mV
  // DEBUG_PRINT("voltageSupply:");
  // DEBUG_PRINTLN(voltageSupply);

  int32_t dilkuInputVoltage      = ads2.readADC_Differential_0_1();  //solar panel
  int32_t dilkuOutputVoltage     = ads2.readADC_Differential_2_3();  //output
  // DEBUG_PRINT("dilkuInputVoltage:");
  // DEBUG_PRINT(dilkuInputVoltage);
  // DEBUG_PRINT(", dilkuOutputVoltage:");
  // DEBUG_PRINT(dilkuOutputVoltage);
  
  float loadvoltage = (dilkuOutputVoltage * MVOLTDILEKADC2 * KOEF_OUTPUT_VOLTAGE) / V2MV; // 13.0f;
  
  if (loadvoltage > MIN && loadvoltage < MAX) {
    voltageRegOut = loadvoltage;
    voltageRegOutMin   = min(loadvoltage, voltageRegOutMin);
    voltageRegOutMax   = max(loadvoltage, voltageRegOutMax);
    // DEBUG_PRINTLN(voltageRegOutMin);
    // DEBUG_PRINTLN(voltageRegOutMax);
  }

  loadvoltage = dilkuOutputVoltage * MVOLTDILEKADC2 * KOEF_INPUT_VOLTAGE; // 13.0f;
  if (loadvoltage > MIN && loadvoltage < MAX) {
    voltageRegIn = 12.f; //loadvoltage;
    voltageRegInMin    = 12.f; //min(loadvoltage, voltageRegIMin);
    voltageRegInMax    = 12.f; //max(loadvoltage, voltageRegInMax);
  }
  
  if (lastReadADC==0) {
    lastReadADC = millis();
  }
  
  uint32_t diff = millis()-lastReadADC;
  
  currentRegIn  = ((float)(dilkuInputCurrent * 2 - dilkuSupply) * MVOLTDILEKADC1) / MVAMPERIN / 2; //in Amp example ((15170 * 2 - 25852) * 0.1875) / 40 = ((30340 - 25852) * 0.1875) / 40 = 4488 * 0.1875 / 40
  currentRegInSum += currentRegIn * diff;
  // DEBUG_PRINT("currentRegIn:");
  // DEBUG_PRINTLN(currentRegIn);
  
  currentRegOut = ((float)(dilkuOutputCurrent * 2 - dilkuSupply)   * MVOLTDILEKADC1) / MVAMPEROUT / 2;
  currentRegOutSum += currentRegOut * diff;
  // DEBUG_PRINT("currentRegOut:");
  // DEBUG_PRINTLN(currentRegOut);
  
  intervalMSec += diff;
 
  lastReadADC = millis();
  return true;
}

bool sendDataHA(void *) {
  digitalWrite(STATUS_LED, LOW);
  digitalWrite(BUILTIN_LED, LOW);
  SenderClass sender;

  sender.add("status/" + String(mqtt_topic_relay), relayStatus); //ON, OFF
  
  if (voltageRegInMin<MAX) {
    sender.add("voltageRegInMin",   voltageRegInMin);
  }
  if (voltageRegInMax>MIN) {
    sender.add("voltageRegInMax",   voltageRegInMax);
    sender.add("powerIn",           (currentRegInSum  / (float)intervalMSec) * voltageRegInMax);
  }
  if (voltageRegOutMin<MAX) {
    sender.add("voltageRegOutMin",  voltageRegOutMin);
  }
  if (voltageRegOutMax>MIN) {
    sender.add("voltageRegOutMax",  voltageRegOutMax);
  }
  sender.add("currentRegIn",      currentRegInSum   / (float)intervalMSec);
  if (relayStatus==RELAY_ON) {
    sender.add("currentRegOut",   currentRegOutSum  / (float)intervalMSec);
    sender.add("powerOut",        (currentRegOutSum / (float)intervalMSec) * voltageRegOutMax);
  } else {
    sender.add("currentRegOut",   0);
    sender.add("powerOut",        0);
  }
  sender.add("intervalSec",       (float)intervalMSec/1000.f);
  
  sender.add("NapetiSbernice",    voltageSupply);

  voltageRegInMin   = MAX;
  voltageRegOutMin  = MAX;
  voltageRegInMax   = MIN; 
  voltageRegOutMax  = MIN;
  intervalMSec      = 0;
  currentRegInSum   = 0.f;
  currentRegOutSum  = 0.f;
  
  DEBUG_PRINTLN(F("Calling MQTT"));

  sender.sendMQTT(mqtt_server, mqtt_port, mqtt_username, mqtt_key, mqtt_base);
  digitalWrite(STATUS_LED, HIGH);
  digitalWrite(BUILTIN_LED, HIGH);
  return true;
}

bool sendStatisticHA(void *) {
  digitalWrite(STATUS_LED, LOW);
  digitalWrite(BUILTIN_LED, LOW);
  //printSystemTime();
  DEBUG_PRINTLN(F(" - I am sending statistic to HA"));
  DEBUG_PRINTLN(F("Calling MQTT"));

  SenderClass sender;
  sender.add("VersionSWFotovoltaika", VERSION);
  sender.add("HeartBeat", heartBeat++);
  if (heartBeat % 10 == 0) sender.add("RSSI", WiFi.RSSI());
  
  sender.add("relayOFFVoltage", relayOFFVoltage);
  sender.add("relayONVoltageBig", relayONVoltageBig);
  sender.add("relayONVoltageSmall", relayONVoltageSmall);
  sender.add("duvodZmenyStavuRele", duvodZmenyStavuRele);

  sender.sendMQTT(mqtt_server, mqtt_port, mqtt_username, mqtt_key, mqtt_base);

  digitalWrite(STATUS_LED, HIGH);
  digitalWrite(BUILTIN_LED, HIGH);
  return true;
}


void sendRelayHA(byte akce) {
  digitalWrite(STATUS_LED, LOW);
  digitalWrite(BUILTIN_LED, LOW);
  SenderClass sender;
  sender.add("relayChange", akce);
  sender.add("duvodZmenyStavuRele", duvodZmenyStavuRele);
  sender.add("status/" + String(mqtt_topic_relay), relayStatus); //ON, OFF
  
 
  sender.sendMQTT(mqtt_server, mqtt_port, mqtt_username, mqtt_key, mqtt_base);
  digitalWrite(STATUS_LED, HIGH);
  digitalWrite(BUILTIN_LED, HIGH);
}
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

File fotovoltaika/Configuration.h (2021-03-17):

#ifndef CONFIGURATION_H
#define CONFIGURATION_H

#include <ESP8266WiFi.h>          //https://github.com/esp8266/Arduino
#include <WiFiManager.h>          //https://github.com/tzapu/WiFiManager
#include <Ticker.h>
#include "Sender.h"
#include <Wire.h>
#include <Adafruit_ADS1015.h>
//#include <Adafruit_INA219.h>
#include <FS.h>          //this needs to be first
#include <DoubleResetDetector.h>      //https://github.com/khoih-prog/ESP_DoubleResetDetector

//SW name & version
#define     VERSION                          "1.02"
#define     SW_NAME                          "Fotovoltaika"

#define timers
#define ota
#define verbose

#define AUTOCONNECTNAME   HOSTNAMEOTA
#define AUTOCONNECTPWD    "password"

#ifdef ota
#include <ArduinoOTA.h>
#define HOSTNAMEOTA   "fotovoltaika"
#endif


// Number of seconds after reset during which a
// subseqent reset will be considered a double reset.
#define DRD_TIMEOUT 2
// RTC Memory Address for the DoubleResetDetector to use
#define DRD_ADDRESS 0

#define CONFIG_PORTAL_TIMEOUT 60 //jak dlouho zustane v rezimu AP nez se cip resetuje
#define CONNECT_TIMEOUT 120 //jak dlouho se ceka na spojeni nez se aktivuje config portal

#ifdef verbose
  #define DEBUG_PRINT(x)                     Serial.print (x)
  #define DEBUG_PRINTDEC(x)                  Serial.print (x, DEC)
  #define DEBUG_PRINTLN(x)                   Serial.println (x)
  #define DEBUG_PRINTF(x, y)                 Serial.printf (x, y)
  #define PORTSPEED 115200             
  #define DEBUG_WRITE(x)                     Serial.write (x)
  #define DEBUG_PRINTHEX(x)                  Serial.print (x, HEX)
  #define SERIAL_BEGIN                       Serial.begin(PORTSPEED)
#else
  #define DEBUG_PRINT(x)
  #define DEBUG_PRINTDEC(x)
  #define DEBUG_PRINTLN(x)
  #define DEBUG_PRINTF(x, y)
  #define DEBUG_WRITE(x)
#endif 


//All of the IO pins have interrupt/pwm/I2C/one-wire support except D0.
#define STATUS_LED                          BUILTIN_LED //status LED
#define LED2PIN                             D3 //stav rele, 10k Pull-up     GPIO00
#define RELAY1PIN                           D8 //pin rele 1                 GPIO16
#define RELAY2PIN                           D6 //pin rele 2, MISO           GPIO12
#define PIRPIN                              D5 //pin pir sensoru, SCK       GPIO14
//SDA                                       D2 //                           GPIO04
//SCL                                       D1 //                           GPIO05
//BUILTIN_LED                               D4 //10k Pull-up, BUILTIN_LED   GPIO02


static const char* const      mqtt_server                    = "192.168.1.56";
static const uint16_t         mqtt_port                      = 1883;
static const char* const      mqtt_username                  = "datel";
static const char* const      mqtt_key                       = "hanka12";
static const char* const      mqtt_base                      = "/home/SolarMereni";
static const char* const      static_ip                      = "192.168.2.116";
static const char* const      static_gw                      = "192.168.2.1";
static const char* const      static_sn                      = "255.255.255.0";
static const char* const      mqtt_topic_weather             = "/home/Meteo/Temperature";
static const char* const      mqtt_topic_relay               = "relay";                     //cmnd/relay; status/relay
static const char* const      mqtt_topic_restart             = "restart";
static const char* const      mqtt_topic_relayONVoltageBig   = "relayONVoltageBig";
static const char* const      mqtt_topic_relayONVoltageSmall = "relayONVoltageSmall";
static const char* const      mqtt_topic_relayOFFVoltage     = "relayOFFVoltage";
static const char* const      mqtt_topic_forecast            = "forecast";


#define         CURRENT_UNIT     "A"
#define         VOLTAGE_UNIT     "V"
#define         POWER_UNIT       "W"
#define         MIN_UNIT         "m"
#define         AH_UNIT          "Ah"
#define         V2MV              1000.f  //prevod volt na milivolt Y(in milivolt) = X(in volt) * V2MV

#define LCDADDRESS  0x27
#define LCDCOLS     20
#define LCDROWS     4

#define CFGFILE "/config.json"
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

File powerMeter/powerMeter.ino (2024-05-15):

/*
--------------------------------------------------------------------------------------------------------------------------
POWERMETER - shows values from FV
Petr Fory pfory@seznam.cz
GIT - https://github.com/pfory/
*/

#include "Configuration.h"

bool                  dispClear                   = false;
bool                  vytezovac                   = false;
uint8_t               teplotaBojler               = 0;
uint32_t              lastPulse1                  = 0;

LiquidCrystal_I2C lcd(LCDADDRESS,LCDCOLS,LCDROWS);  // set the LCD
#define PRINT_SPACE  lcd.print(" ");
volatile bool showDoubleDot                 = false;
//#define DISPLAY_MAIN                         0

//navrhar - https://maxpromer.github.io/LCD-Character-Creator/
byte customChar[] = {
  B01110,
  B01010,
  B01110,
  B00000,
  B00000,
  B00000,
  B00000,
  B00000
};


ADC_MODE(ADC_VCC); //vcc read

const byte ROWS = 4; //four rows
const byte COLS = 4; //three columns
char keys[ROWS][COLS]                 = {
                                            {'1','2','3','A'},
                                            {'4','5','6','B'},
                                            {'7','8','9','C'},
                                            {'*','0','#','D'}
};
byte rowPins[ROWS]                    = {7,6,5,4}; //connect to the row pinouts of the keypad
byte colPins[COLS]                    = {3,2,1,0}; //connect to the column pinouts of the keypad

//MQTT callback
void callback(char* topic, byte* payload, unsigned int length) {
  // char * pEnd;
  // long int valL;
  String val =  String();
  DEBUG_PRINT("Message arrived [");
  DEBUG_PRINT(topic);
  DEBUG_PRINT("] ");
  for (unsigned int i=0;i<length;i++) {
    DEBUG_PRINT((char)payload[i]);
    val += (char)payload[i];
  }
  DEBUG_PRINTLN();
  
  if (strcmp(topic, (String(mqtt_base) + "/" + String(mqtt_topic_restart)).c_str())==0) {
    DEBUG_PRINT("RESTART");
    ESP.restart();
  } else if (strcmp(topic, (String(mqtt_base) + "/" + String(mqtt_topic_netinfo)).c_str())==0) {
    sendNetInfoMQTT();
  } else if (strcmp(topic, (String(mqtt_pip2424) + "/masterstatus").c_str())==0) {
    lcd.setCursor(0,0);
    if (val=="Line") {
      lcd.print("LIN");
    } else if (val=="Battery") {
      lcd.print("BAT");
    }
  } else if (strcmp(topic, (String(mqtt_pip2424) + "/charge").c_str())==0) {
    lcd.setCursor(4,0);
    if (val=="0") {
      lcd.print("CUT");
    } else if (val=="1") {
      lcd.print("CSO");
    } else if (val=="2") {
      lcd.print("SNU");
    } else if (val=="3") {
      lcd.print("OSO");
    }
  } else if (strcmp(topic, (String(mqtt_pip2424) + "/status").c_str())==0) {
    lcd.setCursor(8,0);
    if (val=="bat") {
      lcd.print("SBU");
    } else if (val=="sol") {
      lcd.print("SOL");
    } else if (val=="uti") {
      lcd.print("UTI");
    }
  } else if (strcmp(topic, (String(mqtt_pip2424) + "/pvEstimateToday").c_str())==0) {
    lcd.setCursor(0,1);
    char temp[5];
    snprintf (temp,5,"%1.2f",val.toFloat());
    lcd.print(temp);
    lcd.print("/");
  } else if (strcmp(topic, (String(mqtt_pip2424) + "/pvEstimateTomorow").c_str())==0) {
    lcd.setCursor(5,1);
    char temp[5];
    snprintf (temp,5,"%1.2f",val.toFloat());
    lcd.print(temp);
  } else if (strcmp(topic, (String(mqtt_pip2424) + "/powerFVToday").c_str())==0) {
    lcd.setCursor(0,2);
    char temp[5];
    snprintf (temp,5,"%1.2f",val.toFloat());
    lcd.print(temp);
    lcd.print("/");
  } else if (strcmp(topic, (String(mqtt_pip2424) + "/utiToday").c_str())==0) {
    lcd.setCursor(5,2);
    char temp[5];
    snprintf (temp,5,"%2.2f",val.toFloat());
    lcd.print(temp);
  } else if (strcmp(topic, (String(mqtt_pip2424) + "/pvchargew").c_str())==0) {
    lcd.setCursor(0,3);
    char temp[5];
    snprintf (temp,5,"%4d",(int)val.toInt());
    lcd.print(temp);
    lcd.print("/");
  } else if (strcmp(topic, (String(mqtt_pip2424) + "/acoutw").c_str())==0) {
    lcd.setCursor(5,3);
    char temp[5];
    snprintf (temp,5,"%4d",(int)val.toInt());
    lcd.print(temp);
    lcd.print("/");
  } else if (strcmp(topic, (String(mqtt_pip2424) + "/utiPower").c_str())==0) {
    lcd.setCursor(10,3);
    char temp[5];
    snprintf (temp,5,"%4d",(int)val.toInt());
    lcd.print(temp);
    lcd.print("W");
  } else if (strcmp(topic, (String(mqtt_pip2424) + "/battcappa").c_str())==0) {
    lcd.setCursor(16,3);
    char temp[4];
    snprintf (temp,4,"%3d",(int)val.toInt());
    lcd.print(temp);
    lcd.print("%");
  } else if (strcmp(topic, (String(mqtt_pip2424) + "/battv").c_str())==0) {
    lcd.setCursor(15,2);
    char temp[5];
    snprintf (temp,5,"%3.1f",val.toFloat());
    lcd.print(temp);
    lcd.print("V");
  } else if (strcmp(topic, (String(mqtt_pip2424) + "/load").c_str())==0) {
    lcd.setCursor(10,2);
    char temp[4];
    snprintf (temp,4,"%3d",(int)val.toInt());
    lcd.print(temp);
    lcd.print("%");
  } else if (strcmp(topic, (String(mqtt_bojler) + "/tBojler2").c_str())==0) {
    teplotaBojler = (int)val.toInt();
  } else if (strcmp(topic, (String(mqtt_solarEnergyMeter) + "/pulseLength1").c_str())==0) {
    lastPulse1 = millis();
    lcd.setCursor(10,1);
    char temp[5];
    snprintf (temp,5,"%4d", (int)(3600.f/((float)val.toInt()/1000.f)));
    lcd.print(temp);
  } else if (strcmp(topic, (String(mqtt_solarEnergyMeter) + "/pulseLength2").c_str())==0) {
    lcd.setCursor(14,1);
    lcd.print("/");
    char temp[5];
    snprintf (temp,5,"%4d", (int)(3600.f/((float)val.toInt()/1000.f)));
    lcd.print(temp);
    lcd.print("W");
  } else if (strcmp(topic, (String(mqtt_vytezovac) + "/POWER").c_str())==0) {
    if (val=="ON") {
      vytezovac = true;
    } else {
      vytezovac = false;
    }
  } else if (strcmp(topic, (String(mqtt_base) + "/" + String(mqtt_config_portal)).c_str())==0) {
    startConfigPortal();
  } else if (strcmp(topic, (String(mqtt_base) + "/" + String(mqtt_config_portal_stop)).c_str())==0) {
    stopConfigPortal();
  }
}
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

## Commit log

2019-04-02 monitor vystupu regulatoru
2019-05-10 + schema ADC
    [adc.brd, adc.sch]
2019-05-17 oprava statusu
    [napeti.brd, napeti.sch]
2019-05-21 upravy desek
    [adc.brd, adc.sch, deska.brd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]
2019-07-08 uprava desky ovladani rele
    [deska.brd, deska.sch, proud.brd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]
2019-07-08 uprava desky
    [deska.brd, deska.sch]
2019-07-17 zmena odporu delice
    [deska.brd, deska.sch]
2019-08-05 + desky
    [Adafruit_INA219_CurPowerMonitor.brd, Adafruit_INA219_CurPowerMonitor.sch, INA219 FeatherWing.brd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]
2019-08-22 + displej
    [napeti.brd, napeti.sch]
2019-09-15 voltage to 12V
2019-09-16 prodloužení intervalu sepnutí relé na 1 hodinu dělení proudu 2, nevím proč vychází proud 2x více než ve skutečnosti je, zjistit
    [napeti.brd, napeti.sch]
2019-09-17 + schema
    [schema.sch]
2019-09-22 měření napětí prohození INA na výstup vstup konstantně 12V
2019-09-24 oprava stavu ledky po startu
2019-10-01 ota zapnuti
    [Configuration.h]
2019-10-01 nove zobrazeni cisel na displeji
    [Configuration.h]
2019-10-03 oprava chyb
    [Configuration.h]
2019-10-03 oprava pozice na displeji
    [Configuration.h]
2019-10-04 pir bez interruptu
    [Configuration.h]
2019-10-10 uprava desky pro mereni napeti pro JST-XH konektor
    [napeti.brd, napeti.sch]
2019-10-10 zmena na konektory JST-XH
    [napeti.brd, napeti.sch]
2019-10-28 zmena delicu
    [napeti.brd, napeti.sch]
2019-10-30 prepocet napeti vstupu a vystupu
    [Configuration.h]
2019-10-30 zmena usporadani displeje
    [Configuration.h]
2019-10-30 posilani spinacich napeti MQTT
    [Configuration.h]
2019-10-31 uprava spinani rele
    [Configuration.h]
2019-11-01 - defaulty pro napeti na 121V - uprava aby se neposilali spatne hodnoty napeti
2019-11-05 prodleva mezi 1-0 a 0-1 na 60 sec v 0.85
    [Configuration.h]
2019-11-10 auto pri startu
    [Configuration.h]
2019-11-17 patch na neustale zasilani zprav manualRelay
    [Configuration.h]
2019-11-25 0.88 + zobrazeni ocekavaneho vykonu na displeji
    [Configuration.h]
2019-11-27 spravne zobrazovani FP
    [Configuration.h]
2019-11-28 - vypnuti rele pokud na nasledujici den neni dobra predpoved
    [Configuration.h]
2019-12-02 0.92 prodlozeni intervalu mezi rozepnutim rele a opetovnym sepnutim na 10 minut
    [Configuration.h]
2019-12-03 0.93 zmena limitu pro predpoved vykonu na dalsi den
    [Configuration.h]
2019-12-05 + vytezovac
    [Configuration.h]
2019-12-05 0.02 zmena topicu
    [Configuration.h]
2019-12-06 posilani statusu
    [Configuration.h]
2019-12-06 zmena topicu
    [Configuration.h]
2019-12-25 posilani rssi jednou za 10 minut kvuli tomu, ze to dlouho trva
    [Configuration.h]
2020-02-14 update sender
    [Configuration.h]
2020-02-19 zmena delay na 2minuty
    [Configuration.h]
2020-03-26 zmena topicu pro rele
    [Configuration.h]
2020-04-20 zmena proudu na 6A
    [Configuration.h]
2020-05-07 změna limitu 2A-4A
    [Configuration.h]
2020-05-12 + podminka na vypnuti kdyz odber je vetsi nez prikon
    [Configuration.h]
2020-07-23 v 1.00 - opraveny stavy rele
    [Configuration.h]
2020-08-05 include do configu
    [Configuration.h]
2020-08-05 1.02 add doubleresetdetector
    [Configuration.h]
2021-03-17 + powerMeter
    [Configuration.h]
2021-04-19 vypinani displeje 22-06
    [Configuration.h]
2021-04-20 oprava chyby zhasinani displeje
    [Configuration.h]
2021-11-30 + config portal
    [Configuration.h]
2022-03-09 uprava zobrazeni + teplota bojler + watty vstup a vystup
    [Configuration.h]
2022-03-11 oprava vypoctu vystupni energie
    [Configuration.h]
2022-03-24 zmena mqtt pro vytezovac
    [Configuration.h]
2022-06-14 uprava topicu pro vytezovac
    [Configuration.h]
2023-03-15 uprava mqtt sablony
    [Configuration.h]
2024-02-04 lokalni time server
    [Configuration.h]
